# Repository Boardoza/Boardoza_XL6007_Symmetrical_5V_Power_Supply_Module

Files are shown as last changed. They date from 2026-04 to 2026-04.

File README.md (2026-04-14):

# Boardoza XL6007 Symmetrical ±5V Power Supply Module

The **Boardoza XL6007** is a high-efficiency **DC-DC step-up switching regulator module** designed to generate a **symmetrical ±5V output** from a **single supply** input source. Built around the **XL6007E1** high-frequency switching regulator, this board provides both +5V and -5V outputs, making it ideal for analog and dual-supply applications.

Thanks to its fixed **400kHz switching frequency** and integrated boost converter topology, the module ensures stable, efficient voltage conversion with minimal external components. The symmetrical output capability allows balanced current draw from both rails, supporting up to **500mA total output current**. This makes it especially suitable for operational amplifier circuits, sensor interfaces, audio preamplifiers, and other low-power analog designs requiring dual-polarity supply.

## [Click here to purchase!](https://www.ozdisan.com/ureticiler/boardoza)

| Front Side | Back Side |
|:---:|:---:|
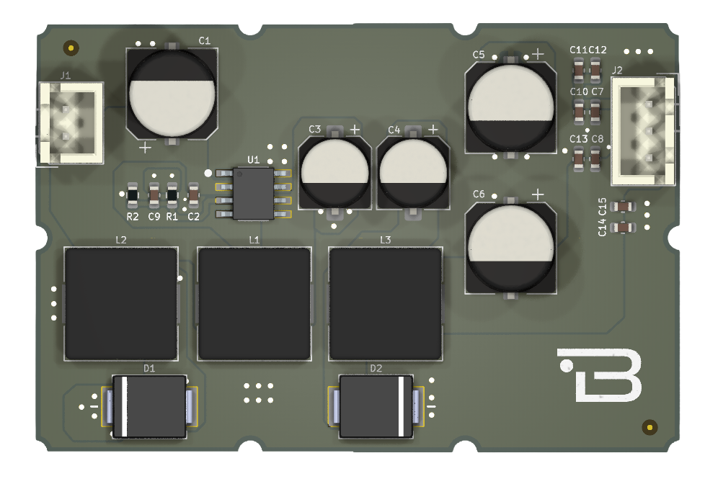
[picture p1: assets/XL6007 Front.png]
B-XL6007-BRK Front
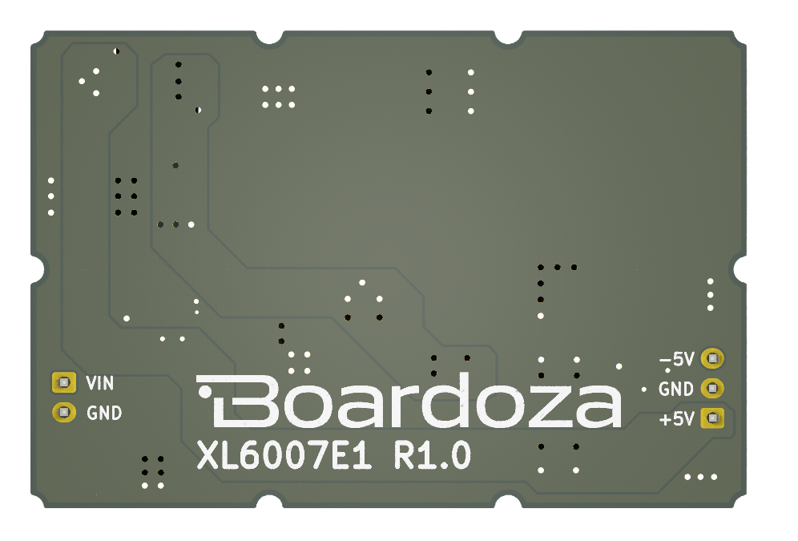
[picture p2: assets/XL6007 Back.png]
B-XL6007-BRK Back
|  |  |

---

## Key Features

- **Symmetrical ±5V Output:** Generates both **+5V and -5V** from a single input supply.  
- **Boost Converter Topology:** Based on the **XL6007E1** high-efficiency DC-DC step-up regulator.  
- **High Output Capability:** Supports up to **500mA total output current** (shared between outputs).  
- **High Switching Frequency:** Fixed **400kHz** operation for stable and efficient performance.  
- **Good Efficiency:** Up to **~90% efficiency** depending on load and conditions.  

---

## Technical Specifications

**Model:** XL6007  
**Manufacturer:** Boardoza  
**Manufacturer IC:** XLSEMI  
**Topology:** Boost Switching Regulator (Configured for Dual Output)  
**Input Voltage:** 3V DC to +12V DC  
**Output Voltage:** +5V and -5V  
**Maximum Output Current:** Up to 500mA (Total Symmetrical)  
**Switching Frequency:** 400kHz (Fixed)  
**Efficiency:** Up to 90% (IC dependent, application specific)  
**Operating Temperature:** -40°C to +125°C  
**Board Dimensions:** 40mm x 60mm  

---

## Board Pinout

### ( J1 ) Input Connector

| Pin Number | Pin Name | Description |
|:---:|:---:|---|
| 1 | VIN | Supply Voltage Input |
| 2 | GND | Ground |

### ( J2 ) Output Connector

| Pin Number | Pin Name | Description |
|:---:|:---:|---|
| 1 | +5V | Positive 5V Output |
| 2 | GND | Ground |
| 3 | -5V | Negative 5V Output |

---

## Performance Graph

### Output Current vs Input Voltage

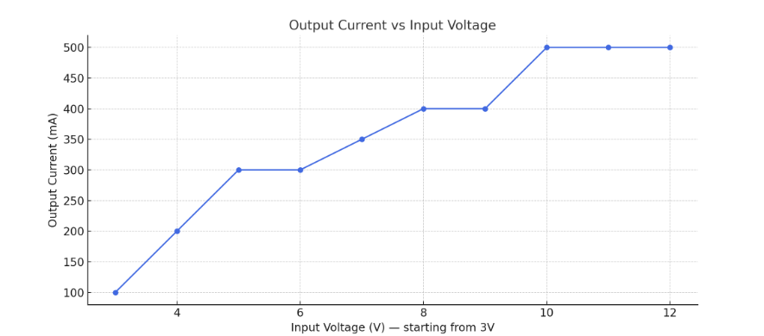
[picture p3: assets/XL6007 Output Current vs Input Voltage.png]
Output Current vs Input Voltage Graph


---

## Board Dimensions

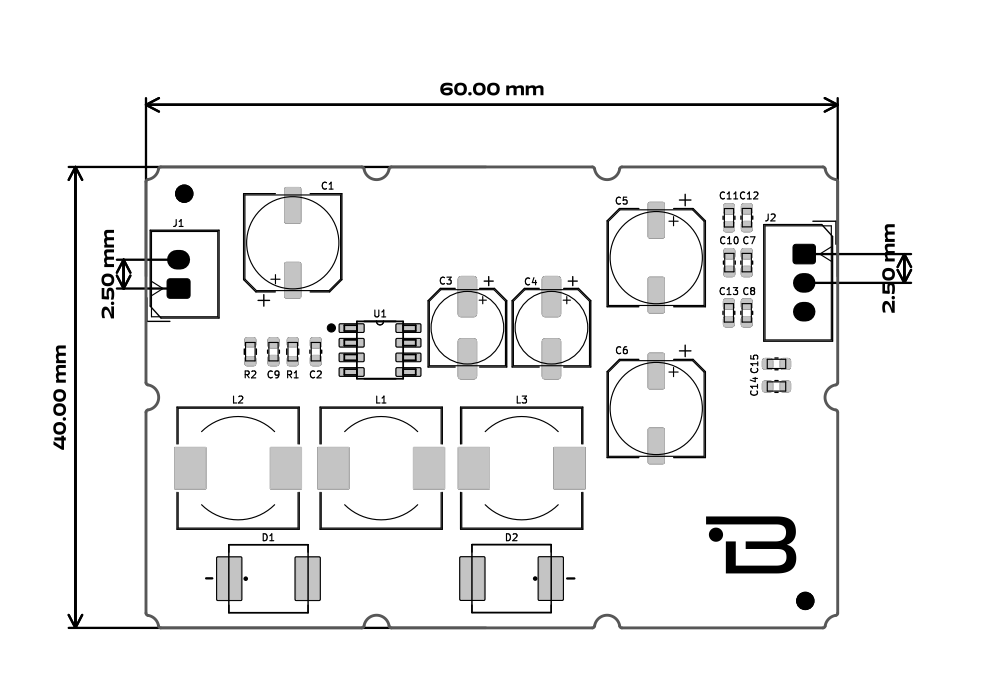
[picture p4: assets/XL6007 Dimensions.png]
B-XL6007-BRK Dimension


---

## Step Files

[Boardoza XL6007E1.step](./assets/XL6007%20Step.step)

---

## Datasheet

[XL6007 Datasheet.pdf](./assets/XL6007%20Datasheet.pdf)

---

## Version History

- V1.0.0 - Initial Release

---

## Support

- If you have any questions or need support, please contact **support@boardoza.com**

---

## **License**
### **Hardware Design**

[][cc-by-sa]

All hardware design files are licensed under [Creative Commons Attribution-ShareAlike 4.0 International License][cc-by-sa].

[cc-by-sa]: http://creativecommons.org/licenses/by-sa/4.0/
[cc-by-sa-shield]: https://img.shields.io/badge/License-CC%20BY--SA%204.0-lightgrey.svg

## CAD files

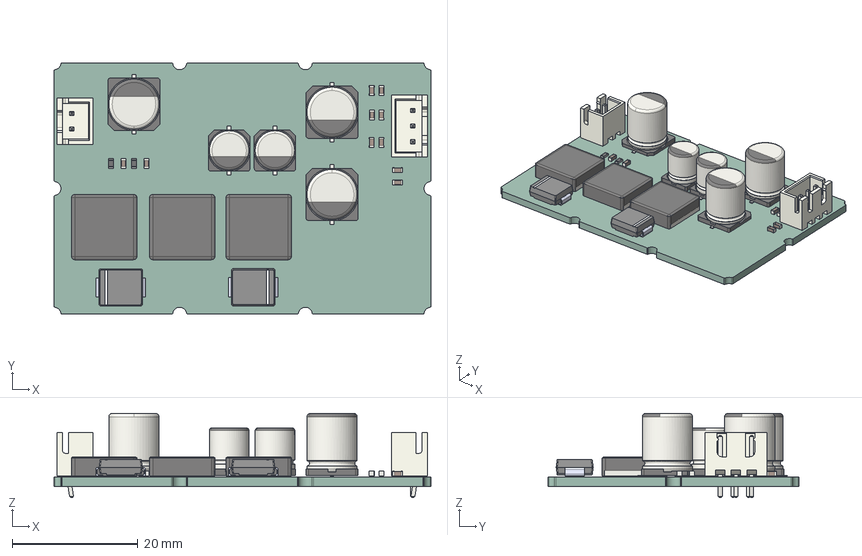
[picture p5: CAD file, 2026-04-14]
assets/XL6007 Step.step
60.0 x 40.0 x 13.4 mm
C_0603_1608Metric x 10
CP_Elec_8x10 x 3
L_Cenker_CKCS8060 x 3
R_0603_1608Metric x 2
SS34 x 2
CP_Elec_6.3x7.7 x 2
JST_XH_B2B-XH-A_1x02_P2.50mm_Vertical
JST_XH_B3B-XH-A_1x03_P2.50mm_Vertical
B-XL6007-BRK_PCB

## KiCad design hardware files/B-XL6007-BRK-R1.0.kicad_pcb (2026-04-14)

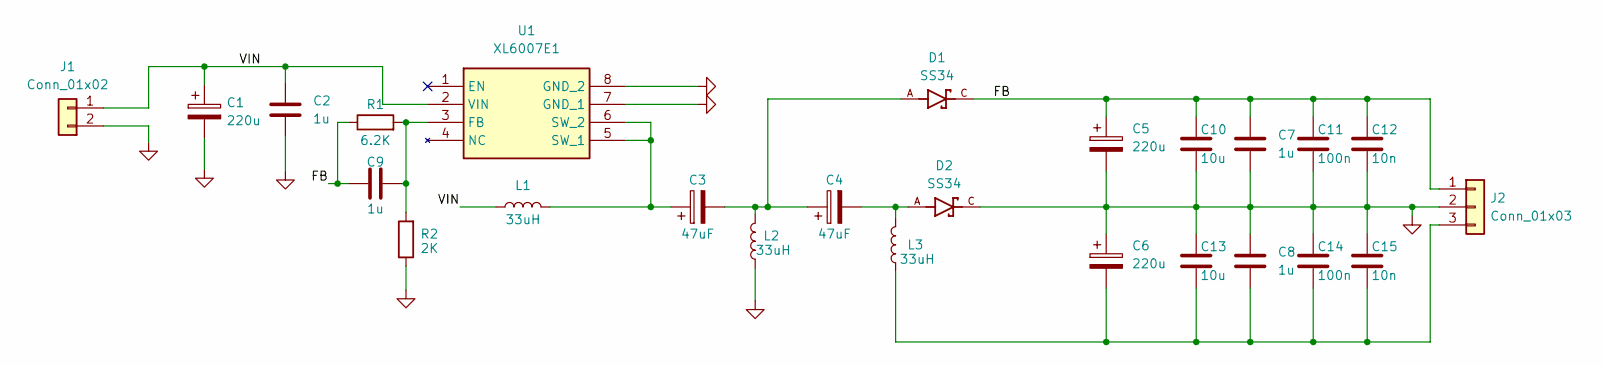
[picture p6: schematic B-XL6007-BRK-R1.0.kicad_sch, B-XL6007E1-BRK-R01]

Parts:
C1, C5, C6: 220u; CP_Elec_8.3x8.3; MPN SVB025M221FABPE50V00A
C2, C7, C8, C9: 1u; C_0603_1608Metric; MPN MCF03KTB250105
C3, C4: 47uF; CP_Elec_6.3x7.7; MPN SC1H476M6L07KVR
C10, C13: 10u; C_0603_1608Metric; MPN MCF03MTX250106
C11, C14: 100n; C_0603_1608Metric; MPN MCF03KTB250104
C12, C15: 10n; C_0603_1608Metric; MPN MCF03KTB500103
D1, D2: SS34; DIO_SS34; PARTREV S2311
J1: Conn_01x02; 2317-02S_1x02_P2.50mm_Vertical; MPN 2317-02S
J2: Conn_01x03; 2317-03S_1x03_P2.50mm_Vertical; MPN 2317-03S
L1, L2, L3: 33uH; L_10.4x10.4_H4.8; MPN CDRH105R-330M
R1: 6.2K; R_0603_1608Metric; MPN 0603SAJ0622T5E
R2: 2K; R_0603_1608Metric; MPN 0603SAJ0202T5E
U1: XL6007E1; SOIC127P600X175-8N; Manufacturer_Part_Number XL6007E1

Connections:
/FB: C5.1, C7.1, C9.1, C10.1, C11.1, C12.1, D1.C, J2.1, R1.1
/VIN: C1.1, C2.1, J1.1, L1.1, U1.2 (VIN)
GND: C1.2, C2.2, C5.2, C6.1, C7.2, C8.1, C10.2, C11.2, C12.2, C13.1, C14.1, C15.1, D2.C, J1.2, J2.2, L2.1, R2.1, U1.7 (GND_1), U1.8 (GND_2)
unnamed: C3.2, C4.1, D1.A, L2.2
unnamed: C4.2, D2.A, L3.2
unnamed: C6.2, C8.2, C13.2, C14.2, C15.2, J2.3, L3.1
unnamed: C9.2, R1.2, R2.2, U1.3 (FB)
unnamed: C3.1, L1.2, U1.5 (SW_1), U1.6 (SW_2)

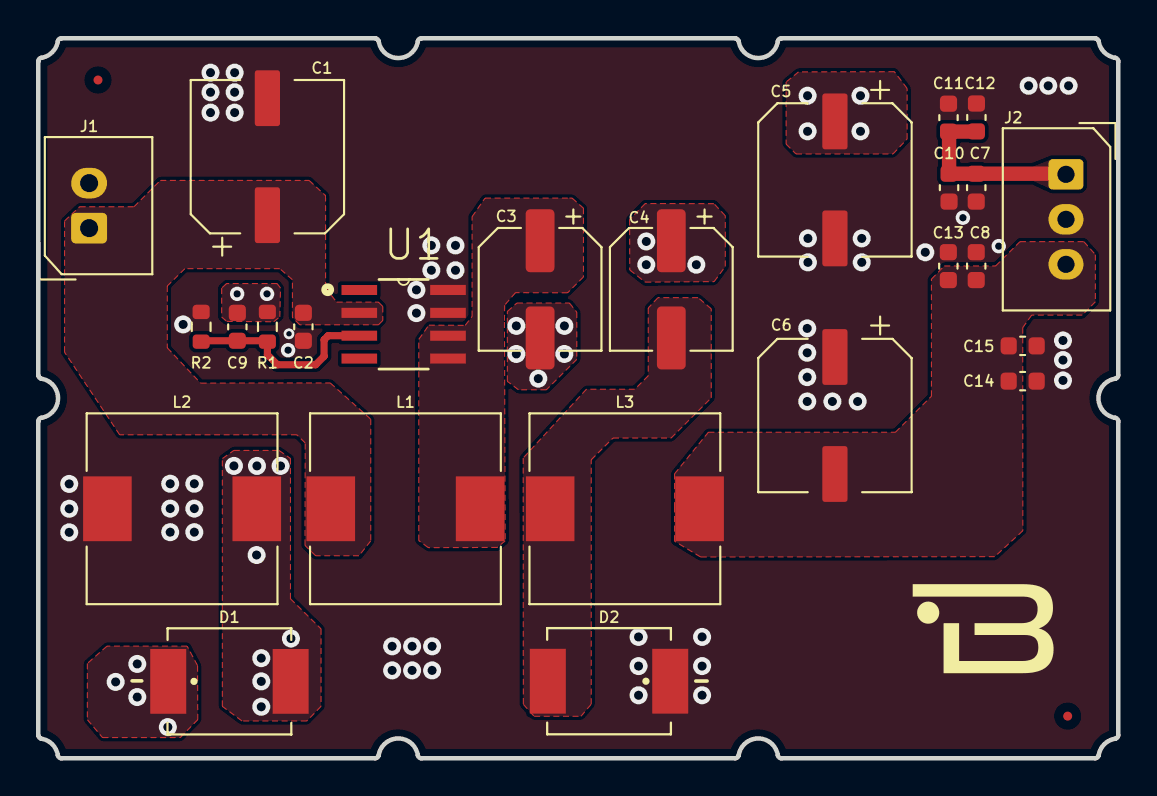
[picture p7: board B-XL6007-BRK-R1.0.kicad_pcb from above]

Board: 2 copper layers, 60.0 x 40.0 mm, 25 parts (0 on the bottom side), 8 nets.

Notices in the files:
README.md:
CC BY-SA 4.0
